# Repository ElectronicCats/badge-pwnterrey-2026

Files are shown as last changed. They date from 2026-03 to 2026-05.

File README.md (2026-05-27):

# Badge PWNTerrey

El **El Badge de Pwnterrey** es un dispositivo de hardware abierto y portátil diseñado para la auditoría de redes inalámbricas y seguridad de radiofrecuencia (WiFi, Bluetooth y NFC). Esta versión utiliza el potente y nuevo chip **ESP32-C5 (Arquitectura RISC-V)**, configurada específicamente para operar en modo **"Headless"** (sin pantalla), permitiendo la interacción total mediante consola serie (CLI) e integrando sensores y emuladores como NFC y GPS externo.

***

## 🚀 Características Principales

### 📶 Conectividad Inalámbrica Avanzada
- **Procesador ESP32-C5**: Chip de doble banda Wi-Fi 6 (2.4 GHz y 5 GHz) y Bluetooth 5 (LE) integrado.
- **Auditoría WiFi**: Soporte para escaneo de APs, rastreo de estaciones, sniffing de paquetes, inyección de tramas de desautenticación, spam de beacons y captura de handshakes.
- **Bluetooth (BLE)**: Capacidad para ejecutar ataques de spam BLE (`blespam`).

### 🏷️ Periféricos y Sensores Integrados
- **Emulador NFC (NT3H2111)**: Chip NTAG I2C 2k que permite actuar en **Modo Tarjeta**. El ESP32 emula una etiqueta pasiva para transferir datos NDEF (URLs, textos, vCards, redes WiFi) a teléfonos móviles o Flipper Zero.
- **Receptor GPS**: Interfaz serial dedicada para capturar coordenadas geográficas en tiempo real (Wardriving) y parsear sentencias NMEA.

### ⚙️ Optimización Headless (Sin Pantalla)
- **Bajo Consumo**: Al eliminar pantallas TFT/OLED y botones físicos, se reduce la huella energética y se maximiza la estabilidad.
- **Control Serial Total**: Una robusta interfaz de comandos (CLI) que permite controlar el 100% de las funciones del dispositivo.

***

## 📋 Especificaciones Técnicas

| Componente | Especificación |
| :--- | :--- |
| **Microcontrolador** | ESP32-C5 ECO1 (Arquitectura RISC-V de 32 bits) |
| **Wi-Fi** | Doble banda 2.4 GHz y 5 GHz (Wi-Fi 6 / 802.11ax) |
| **Bluetooth** | Bluetooth 5.0 (Low Energy - LE) |
| **NFC** | Chip **NT3H2111 (NTAG I2C 2k)** emulador de etiqueta pasiva |
| **GPS** | Interfaz serie dedicada para receptor GPS externo (UART1) |
| **Interfaz de Control**| CLI por Puerto Serie USB (115200 baudios) |
| **Estabilidad** | PSRAM desactivada, Flash configurada a 40MHz |

***

## 🔌 Interfaces y Pinout del ESP32-C5

El circuito integrado ESP32-C5 en su configuración Marauder utiliza los siguientes pines clave:

### 🌐 Conexión NFC (I2C)
El chip NTAG NT3H2111 está conectado a través del bus I2C:
- **SDA**: GPIO 2 (Pin 4)
- **SCL**: GPIO 3 (Pin 5)
- **Field Detect (FD)**: GPIO 6 (Pin 8) *(Detecta cuando un lector NFC externo energiza el campo inductivo)*

### 🛰️ Conexión GPS (UART1)
La comunicación con el módulo GPS se realiza mediante los pines:
- **GPS TX (MCU)**: GPIO 4 *(Hacia el pin RX del GPS)*
- **GPS RX (MCU)**: GPIO 5 *(Desde el pin TX del GPS)*
- **GPS ON/Power**: GPIO 7 *(Control de encendido del módulo GPS)*

***

## ⚡ Primeros Pasos

### 1. Alimentación y Conexión
Puedes alimentar y controlar tu adaptador de dos formas:
- **Conexión Directa USB**: Conéctalo a tu computadora usando un cable USB-C. El puerto creará un puerto COM serial.
- **Integración con Flipper Zero**: Conectado como un Addon GPIO al Flipper Zero, alimentado directamente desde los pines de 3.3V/5V del Flipper y controlado desde su aplicación de terminal.

### 2. Abrir la Terminal Serial
El dispositivo se comunica a **115200 baudios**, sin control de flujo (8N1).

#### 🐧 Linux / macOS
Usa el comando `screen` o `minicom`. Primero identifica el puerto (`/dev/ttyUSBX` o `/dev/ttyACM0`):
```bash
# Con screen (para salir: Ctrl+A, luego K)
screen /dev/ttyUSB0 115200

# Con minicom
sudo minicom -b 115200 -D /dev/ttyUSB0
```

#### 🪟 Windows
Usa clientes como **PuTTY** o **TeraTerm**:
- **Puerto**: COMx (Ver en administrador de dispositivos)
- **Baudrate**: 115200
- **Data bits**: 8
- **Parity**: None
- **Stop bits**: 1
- **Flow control**: None

***

## 🏷️ Control del Emulador NFC

El módulo NFC funciona exclusivamente en **modo emulación de etiqueta (Tag)**. No es un lector; actúa como una tarjeta inteligente pasiva que almacena registros NDEF.

### 🔍 Diagnóstico e Información
- **Escanear bus NFC**:
  ```bash
  nfc scan
  ```
  Realiza un escaneo de hardware (discovery) en los pares de pines del bus I2C para verificar la dirección del chip (`0x55` o `0x2A`).
- **Leer contenido actual de la etiqueta**:
  ```bash
  nfc read
  ```
  Muestra en hexadecimal y ASCII los bloques del 1 al 8 grabados en la memoria del chip NFC.

### ✍️ Escritura de Registros NDEF
Puedes programar el emulador NFC para inyectar diferentes cargas útiles:

- **🔗 Enlace Web (URL)**:
  ```bash
  nfc -u https://electroniccats.com
  ```
- **📝 Texto Plano**:
  ```bash
  nfc -t "Hola Hackers del ESP32-C5"
  ```
- **📇 Tarjeta de Contacto (vCard)**:
  ```bash
  nfc -v "Nombre,Telefono,Email"
  # Ejemplo:
  nfc -v "Electronic Cats,5551234567,info@electroniccats.com"
  ```
- **📶 Credenciales de Red WiFi**:
  ```bash
  nfc -w "SSID,Password,Autenticacion"
  # Ejemplo:
  nfc -w "MiRedSegura,Clave1234,WPA2"
  ```

Una vez ejecutado el comando con éxito, cualquier dispositivo móvil o lector NFC (como un Flipper Zero) que se acerque al sensor detectará la etiqueta y ejecutará la acción (abrir el link, importar el contacto o conectarse al WiFi).

***

## ⚙️ Configuración y Compilación de Firmware

Si deseas compilar o realizar modificaciones en el firmware, debes seguir estas recomendaciones específicas para el hardware ESP32-C5:

Clonar el [repositorio](https://github.com/ElectronicCats/badge-pwnterrey-2026)

### 🛠️ Configuración en configs.h
Asegúrate de que en el archivo [configs.h](file:///run/media/omaro/8C96D9BF96D9AA4A/ESP32Marauder/ESP32Marauder/esp32_marauder/configs.h) la definición activa para la placa sea:
```cpp
#define MARAUDER_FLIPPER_C5
```
Esta definición configurará automáticamente la ausencia de pantalla (`TFT_CS -1`), habilitará `HAS_BT`, `HAS_GPS` y `HAS_NFC` con sus respectivos mapeos de pines.

### ⚠️ Parámetros de Compilación en Arduino IDE
Debido al estado actual del soporte del chip, aplica las siguientes configuraciones de carga:
- **Placa**: ESP32C5 Dev Module
- **Arquitectura**: RISC-V (Compiler optimization)
- **Flash Frequency**: **40MHz** (Recomendado para máxima estabilidad)
- **Partition Scheme**: Minimal SPIFFS / No OTA (Para maximizar el espacio de programa y SPIFFS)
- **PSRAM**: Desactivada (Disabled)
- **Modo de Carga**: Inserte el dispositivo en modo Bootloader manteniendo presionado el botón Boot mientras conecta el USB si no es detectado automáticamente.

***

## ⌨️ Consola de Comandos Completa (CLI Reference)

A continuación se detalla la lista de comandos disponibles en el intérprete de comandos serial:

### 🛠️ Comandos de Administración

| Comando | Sintaxis | Descripción |
| :--- | :--- | :--- |
| `help` | `help` | Muestra la lista de comandos con su formato de ayuda. |
| `info` | `info` | Muestra información del sistema, compilación y hardware. |
| `reboot` | `reboot` | Reinicia el microcontrolador. |
| `channel` | `channel [-s <canal>]` | Muestra o cambia el canal WiFi activo. |
| `settings` | `settings [-s <setting> <enable/disable>]` | Muestra, modifica o reinicia (`-r`) los ajustes internos. |
| `spiffs` | `spiffs [ls / read <file> / rm <file> / format]`| Administra la memoria flash interna (SPIFFS). |
| `led` | `led -s <hex color> / -p <rainbow>` | Cambia el color del led de estado. |

### 📶 Auditoría WiFi (Sniffing & Scanning)

| Comando | Sintaxis | Descripción |
| :--- | :--- | :--- |
| `scanap` | `scanap` | Busca puntos de acceso (APs) inalámbricos cercanos. |
| `scansta` | `scansta` | Busca estaciones y clientes conectados. |
| `stopscan` | `stopscan` | Detiene inmediatamente cualquier escaneo en curso. |
| `list` | `list [-a / -s / -c / -t]` | Muestra listas cargadas (`-a` APs, `-s` SSIDs, `-c` Clientes). |
| `select` | `select -a/-s/-c <indices>` | Selecciona elementos por índice para interactuar. |
| `clearlist`| `clearlist -a/-c/-s` | Limpia los registros de la memoria RAM. |
| `ssid` | `ssid -a [-g <count> / -n <name>]` | Agrega SSIDs a la lista (`-g` aleatorios, `-n` específicos). |
| `sniffraw` | `sniffraw` | Captura y vuelca todos los paquetes raw recibidos. |
| `sniffbeacon`| `sniffbeacon` | Captura tramas beacon. |
| `sniffprobe`| `sniffprobe` | Captura peticiones probe request de clientes. |
| `sniffpwn` | `sniffpwn` | Sniffer enfocado en capturas de handshakes WPA. |
| `sniffpmkid`| `sniffpmkid [-c <channel>]` | Captura asociaciones PMKID para auditoría WPA2. |

### 💥 Comandos de Ataque WiFi y Bluetooth

| Comando | Sintaxis | Descripción |
| :--- | :--- | :--- |
| `attack` | `attack -t <deauth/beacon/probe/rickroll>` | Inicia ataque de desautenticación, spam de beacons, etc. |
| `blespam` | `blespam -t <apple/google/samsung/windows/all>`| Inicia campañas de spam publicitario Bluetooth BLE. |
| `wardrive` | `wardrive [-s]` | Inicia el modo Wardriving clásico sincronizado con GPS. |

***

## ⚠️ Advertencia de Seguridad

Esta herramienta ha sido diseñada exclusivamente para **fines educativos, pruebas de penetración ética y auditorías de seguridad autorizadas**. 

El uso de este dispositivo para interferir, interceptar o atacar redes e infraestructura ajena sin el consentimiento previo por escrito del propietario es **estrictamente ilegal**. Los desarrolladores y colaboradores no se hacen responsables del uso indebido de esta herramienta ni de los daños que este pueda causar.

## 📖 Documentación Adicional

- [Marauder App](https://github.com/ElectronicCats/marauder-ui-android-app)
- [Marauder UI Pro](https://github.com/ElectronicCats/marauder-ui-pro)
- [Firmware](https://github.com/ElectronicCats/pwnterrey-2026_Firmware)

## 🤝 Contribuciones

Este es un proyecto de hardware abierto. Las contribuciones son bienvenidas:

1. Haz un fork del repositorio.
2. Crea una nueva rama para tu feature (`git checkout -b feature/AmazingFeature`)
3. Haz commit de tus cambios (`git commit -m 'Add some AmazingFeature'`)
4. Haz push a tu rama (`git push origin feature/AmazingFeature`)
5. Abre un Pull Request

## 📝 Licencia

Este proyecto es de hardware abierto. Consulta los archivos de licencia para más detalles.

## 🏢 Electronic Cats

Desarollado con ❤️ por [Electronic Cats](https://www.electroniccats.com/)

<a href="https://github.com/sponsors/ElectronicCats">

</a>

Electronic Cats invierte tiempo y recursos en proporcionar este diseño de hardware abierto.
Por favor, apoya a Electronic Cats y al hardware abierto comprando productos de Electronic Cats.

## 📞 Contacto y soporte 

- **Website**: [https://www.electroniccats.com/](https://www.electroniccats.com/)
- **GitHub**: [ElectronicCats](https://github.com/ElectronicCats)
- **Issues**: Usa la sección de Issues en GitHub para reportar problemas o sugerir mejoras

## 🙏 Agradecimientos

Gracias a toda la comunidad de hardware abierto y a todas las personas que hacen posibles proyectos como este.

## 🤝 Credits & Ecosystem
- **Hardware & Support**: [Electronic Cats](https://electroniccats.com) 😼
- **Original Firmware**: [justcallmekoko](https://github.com/justcallmekoko)
- **UI Maintenance**: [michelangelomo](https://github.com/michelangelomo) & [Mikystars](https://github.com/Mikystars)

---
*Developed for the Offensive Security community.* 💀

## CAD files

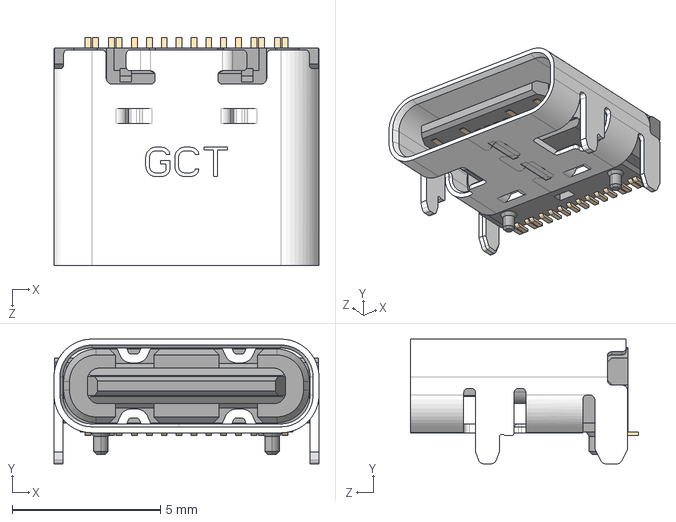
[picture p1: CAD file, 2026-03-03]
hardware/Footprints/3D/USB4105-GF-A.stp
8.94 x 4.21 x 7.70 mm
HSG_默认

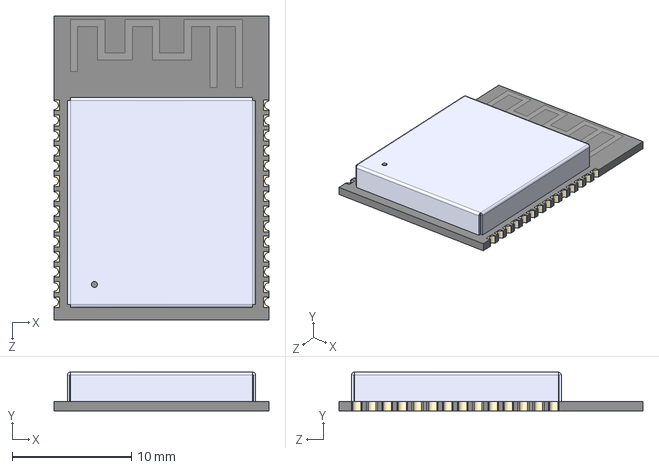
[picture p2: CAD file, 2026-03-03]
hardware/Footprints/3D/ESP32-C6-WROOM-1-N8--3DModel-STEP-56544.STEP
18.0 x 3.25 x 25.5 mm

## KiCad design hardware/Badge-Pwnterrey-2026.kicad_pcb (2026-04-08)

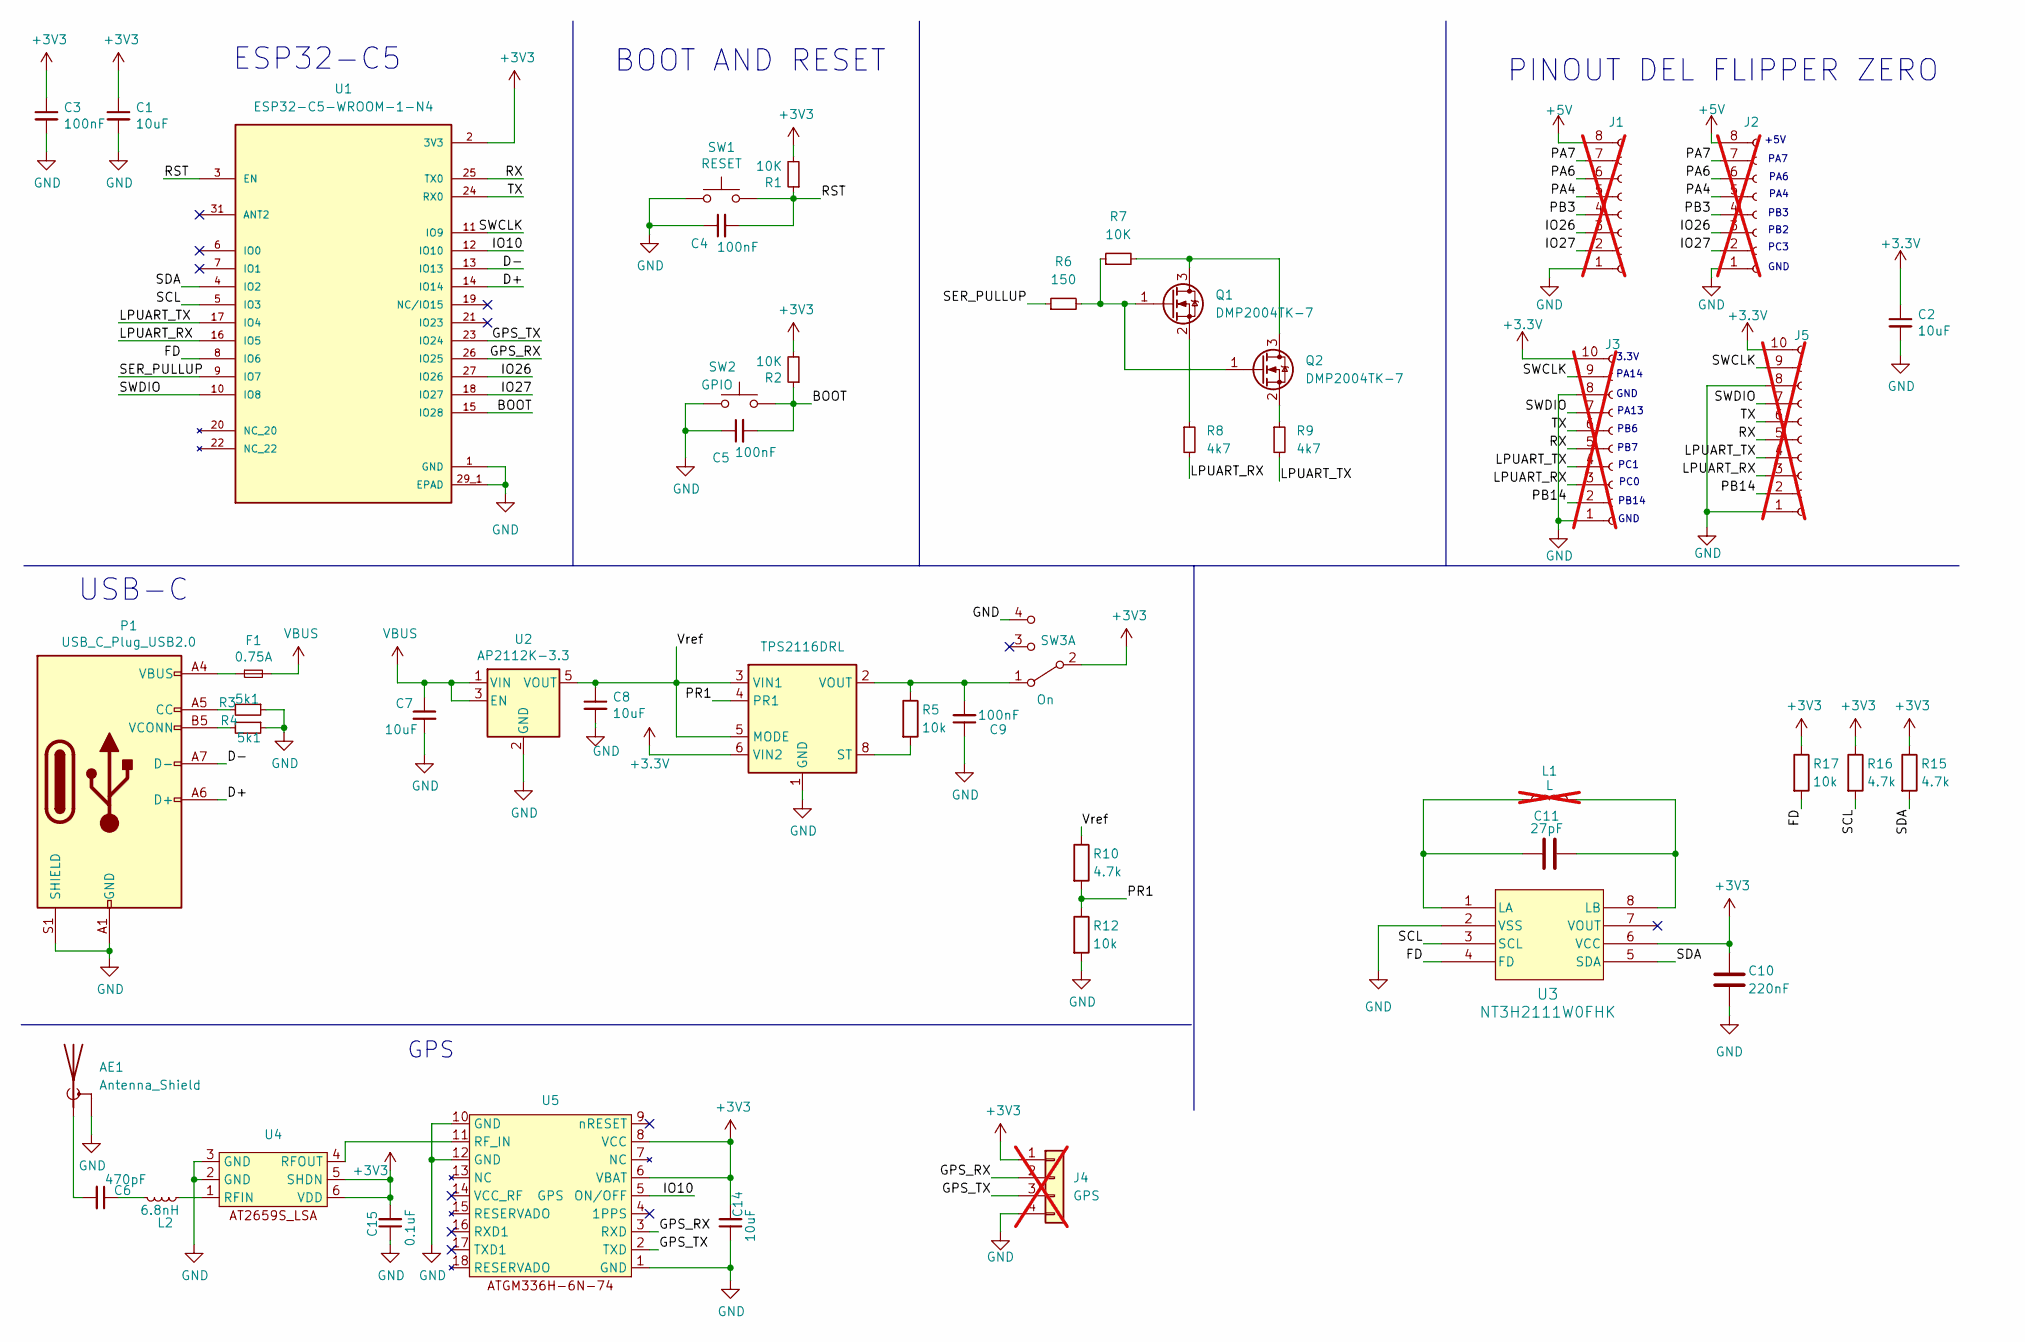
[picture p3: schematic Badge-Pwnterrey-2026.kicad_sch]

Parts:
AE1: Antenna_Shield; U.FL_Molex_MCRF_73412-0110_Vertical; LCSC# C7426714
C1, C2, C7, C8, C14: 10uF; C_0603_1608Metric; LCSC# C85713
C3, C4, C5, C9: 100nF; C_0603_1608Metric; LCSC# C597251
C6: 470pF; C_0603_1608Metric; LCSC# C1620
C10: 220nF; C_0603_1608Metric; LCSC# C344195
C11: 27pF; C_0603_1608Metric; LCSC# C107045
C15: 0.1uF; C_0603_1608Metric; LCSC# C478888
F1: 0.75A; Fuse_0603_1608Metric; LCSC# C182438
J1, J2: Conn_01x08_Socket; PinHeader_1x08_P2.54mm_Vertical; LCSC# C49326132; not fitted
J3, J5: Conn_01x10_Socket; PinHeader_1x10_P2.54mm_Vertical; LCSC# C49326134; not fitted
J4: GPS; PinHeader_1x04_P2.54mm_Vertical; not fitted
L1: L; Untitled; not fitted
L2: 6.8nH; L_0603_1608Metric_Pad1.05x0.95mm_HandSolder; LCSC# C49447
P1: USB_C_Plug_USB2.0; C393939; LCSC# C2760486
Q1, Q2: DMP2004TK-7; SOT-523
R1, R2, R7: 10K; R_0603_1608Metric; LCSC# C217281
R3, R4: 5k1; R_0603_1608Metric; LCSC# C156350
R5, R12, R17: 10k; R_0603_1608Metric; LCSC# C2930027
R6: 150; R_0603_1608Metric; LCSC# C2692872
R8, R9: 4k7; R_0603_1608Metric; LCSC# C394547
R10, R15, R16: 4.7k; R_0603_1608Metric; LCSC# C2907034
SW1: RESET; SW_SPST_TL3342; LCSC# C2886897
SW2: GPIO; SW_SPST_TL3342; LCSC# C2886897
SW3: On; MSK12C02; LCSC# C431540
U1: ESP32-C5-WROOM-1-N4; esp32c5wroom1n4
U2: AP2112K-3.3; SOT-23-5; LCSC# C150742
U3: NT3H2111W0FHK; XQFN8_NT3H2111_NXP-L; LCSC# C710403
U4: LNA; AT2659S-LSA; LCSC# C883443
U5: GPS; GPSM-SMD_ATGM336H; LCSC# C5804601
U7: TPS2116DRL; SOT-583-8; LCSC# C3235557

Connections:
+3.3V: C2.1, J3.10 (Pin_1), J5.10 (Pin_1), U7.6 (VIN2)
+3V3: C1.1, C3.1, C10.1, C14.2, C15.2, J4.1, R1.2, R2.2, R15.1, R16.1, R17.1, SW3.2 (B), U1.2 (3V3), U3.6 (VCC), U4.5 (SHDN), U4.6 (VDD), U5.6 (VBAT), U5.8 (VCC)
+5V: J1.8 (Pin_1), J2.8 (Pin_1)
/BOOT: C5.2, R2.1, SW2.2, U1.15 (IO28)
/D+: P1.A6 (D+), U1.14 (IO14)
/D-: P1.A7 (D-), U1.13 (IO13)
/FD: R17.2, U1.8 (IO6), U3.4 (FD)
/GPS_RX: J4.2, U1.26 (IO25), U5.3 (RXD)
/GPS_TX: J4.3, U1.23 (IO24), U5.2 (TXD)
/IO10: U1.12 (IO10), U5.5 (ON/OFF)
/IO26: J1.3 (Pin_6), J2.3 (Pin_6), U1.27 (IO26)
/IO27: J1.2 (Pin_7), J2.2 (Pin_7), U1.18 (IO27)
/LPUART_RX: J3.3 (Pin_8), J5.3 (Pin_8), R8.2, U1.16 (IO5)
/LPUART_TX: J3.4 (Pin_7), J5.4 (Pin_7), R9.2, U1.17 (IO4)
/PA4: J1.5 (Pin_4), J2.5 (Pin_4)
/PA6: J1.6 (Pin_3), J2.6 (Pin_3)
/PA7: J1.7 (Pin_2), J2.7 (Pin_2)
/PB3: J1.4 (Pin_5), J2.4 (Pin_5)
/PB14: J3.2 (Pin_9), J5.2 (Pin_9)
/PR1: R10.2, R12.1, U7.4 (PR1)
/RST: C4.2, R1.1, SW1.2, U1.3 (EN)
/RX: J3.5 (Pin_6), J5.5 (Pin_6), U1.25 (TX0)
/SCL: R16.2, U1.5 (IO3), U3.3 (SCL)
/SDA: R15.2, U1.4 (IO2), U3.5 (SDA)
/SER_PULLUP: R6.1, U1.9 (IO7)
/SWCLK: J3.9 (Pin_2), J5.9 (Pin_2), U1.11 (IO9)
/SWDIO: J3.7 (Pin_4), J5.7 (Pin_4), U1.10 (IO8)
/TX: J3.6 (Pin_5), J5.6 (Pin_5), U1.24 (RX0)
/Vref: C8.1, R10.1, U2.5 (VOUT), U7.3 (VIN1), U7.5 (MODE)
GND: AE1.2 (Shield), C1.2, C2.2, C3.2, C4.1, C5.1, C7.2, C8.2, C9.1, C10.2, C14.1, C15.1, J1.1 (Pin_8), J2.1 (Pin_8), J3.1 (Pin_10), J3.8 (Pin_3), J4.4, J5.1 (Pin_10), J5.8 (Pin_3), P1.A1 (GND), P1.A12 (GND), P1.B1 (GND), P1.B12 (GND), P1.S1 (SHIELD), R3.1, R4.1, R12.2, SW1.1, SW2.1, SW3.4 (C), U1.1 (GND), U1.28 (GND), U1.29, U1.29_1 (EPAD), U1.29_2 (EPAD), U1.29_3 (EPAD), U1.29_4 (EPAD), U1.29_5 (EPAD), U1.29_6 (EPAD), U1.29_7 (EPAD), U1.29_8 (EPAD), U1.29_9 (EPAD), U1.30 (GND), U1.31 (ANT2), U1.32 (GND), U1.33, U1.34, U1.35, U1.36, U1.37, U2.2 (GND), U3.2 (VSS), U4.2 (GND), U4.3 (GND), U5.1 (GND), U5.10 (GND), U5.12 (GND), U7.1 (GND)
unnamed: AE1.1 (A), C6.2
unnamed: C6.1, L2.2
unnamed: F1.1, P1.A4 (VBUS), P1.A9 (VBUS), P1.B4 (VBUS), P1.B9 (VBUS)
unnamed: P1.A5 (CC), R3.2
unnamed: P1.B5 (VCONN), R4.2
unnamed: Q1.3 (D), Q2.3 (D), R7.2
unnamed: Q1.1 (G), Q2.1 (G), R6.2, R7.1
unnamed: Q1.2 (S), R8.1
unnamed: Q2.2 (S), R9.1
unnamed: C9.2, R5.1, SW3.1 (A), U7.2 (VOUT), U7.7 (VOUT)
unnamed: C11.1, L1.1, U3.1 (LA)
unnamed: C11.2, L1.2, U3.8 (LB)
unnamed: L2.1, U4.1 (RFIN)
unnamed: U4.4 (RFOUT), U5.11 (RF_IN)
unnamed: R5.2, U7.8 (ST)
VBUS: C7.1, F1.2, U2.1 (VIN), U2.3 (EN)

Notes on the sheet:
PB2
GPS
PA14
PC1
PB6
PINOUT DEL FLIPPER ZERO
PA13
GND
ESP32-C5
PB14
USB-C
PB7
3.3V
PC0
+5V
PC3
PA7
PA6
PB3
BOOT AND RESET
PA4

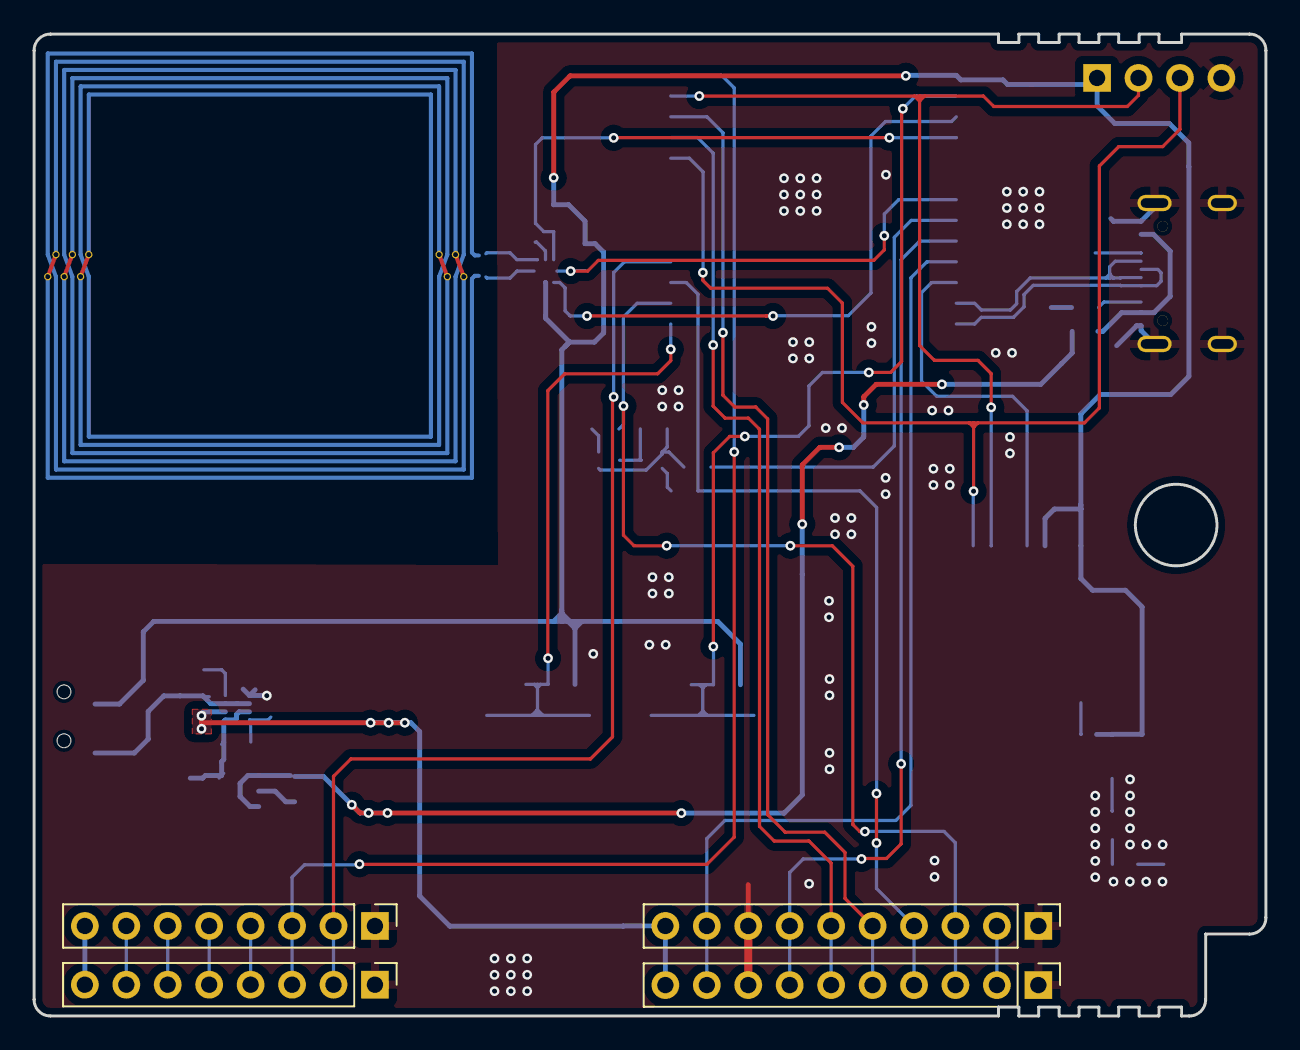
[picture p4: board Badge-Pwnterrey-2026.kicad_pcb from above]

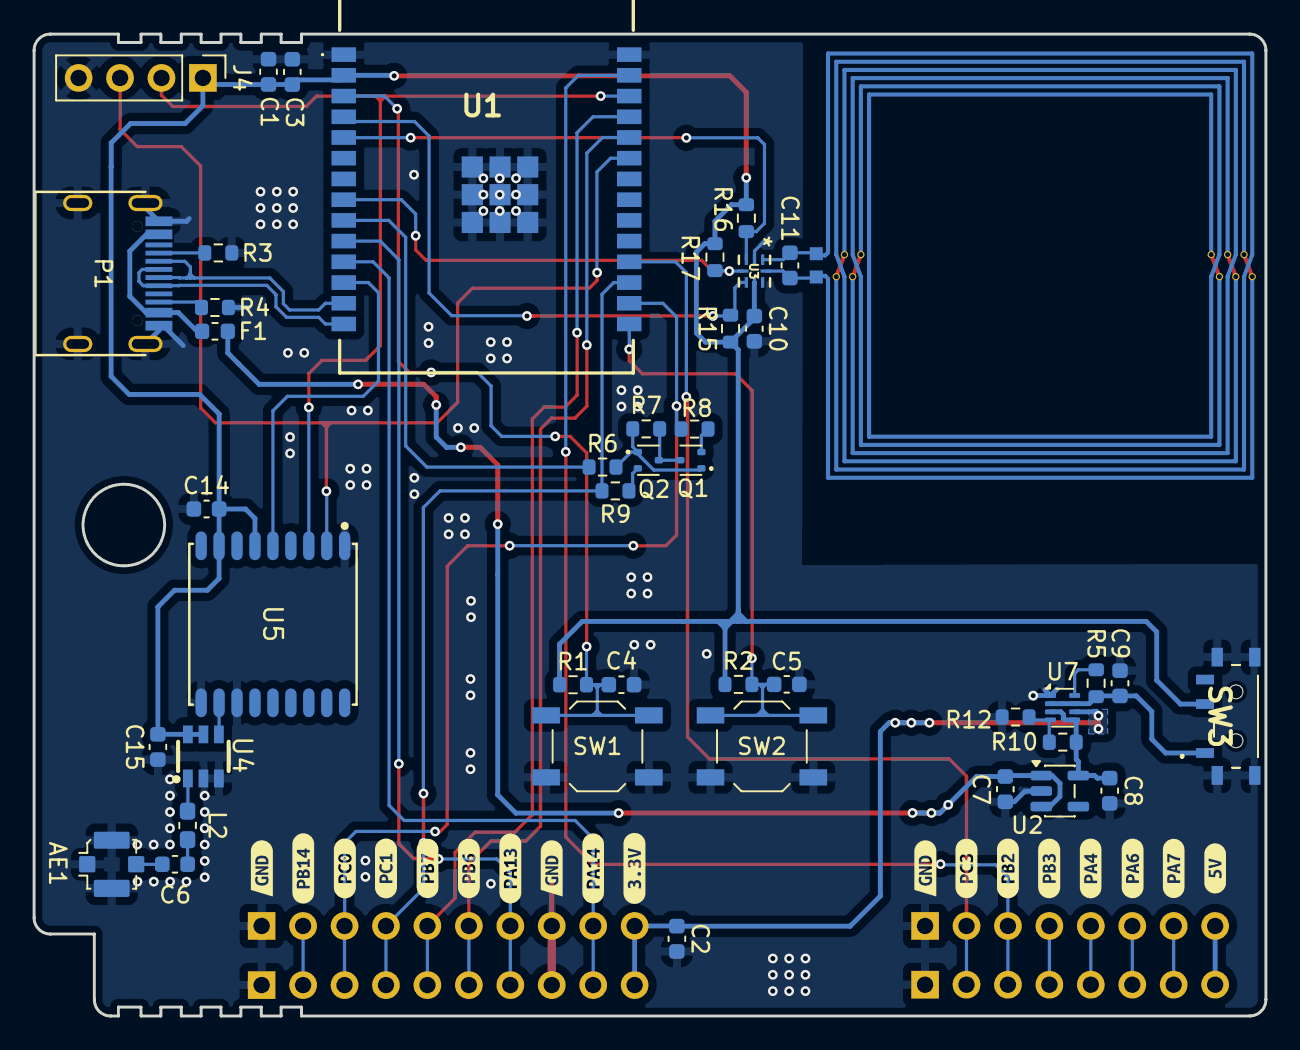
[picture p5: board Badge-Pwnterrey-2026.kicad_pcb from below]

Board: 2 copper layers, 75.5 x 60.2 mm, 66 parts (61 on the bottom side), 46 nets.

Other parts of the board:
kibuzzard-64E4E5CE: G***; kibuzzard-64E4E5CE
kibuzzard-648B91CB: G***; kibuzzard-648B91CB
kibuzzard-648B91E6: G***; kibuzzard-648B91E6
kibuzzard-648B91FC: G***; kibuzzard-648B91FC
kibuzzard-648B93B1: G***; kibuzzard-648B93B1
kibuzzard-648B93BF: G***; kibuzzard-648B93BF
kibuzzard-648B93D2: G***; kibuzzard-648B93D2
kibuzzard-648B93E0: G***; kibuzzard-648B93E0
kibuzzard-648B93EF: G***; kibuzzard-648B93EF
kibuzzard-648B921B: G***; kibuzzard-648B921B
kibuzzard-648B922F: G***; kibuzzard-648B922F
kibuzzard-648B923F: G***; kibuzzard-648B923F
kibuzzard-648B9401: G***; kibuzzard-648B9401
kibuzzard-648B9410: G***; kibuzzard-648B9410
kibuzzard-6488EEAF, kibuzzard-6488EEAF#2, kibuzzard-6488EEAF#3: G***; kibuzzard-6488EEAF
kibuzzard-6488F75A: G***; kibuzzard-6488F75A
